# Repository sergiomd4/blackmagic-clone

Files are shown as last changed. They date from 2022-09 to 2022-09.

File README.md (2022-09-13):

Black Magic Clone
========================================

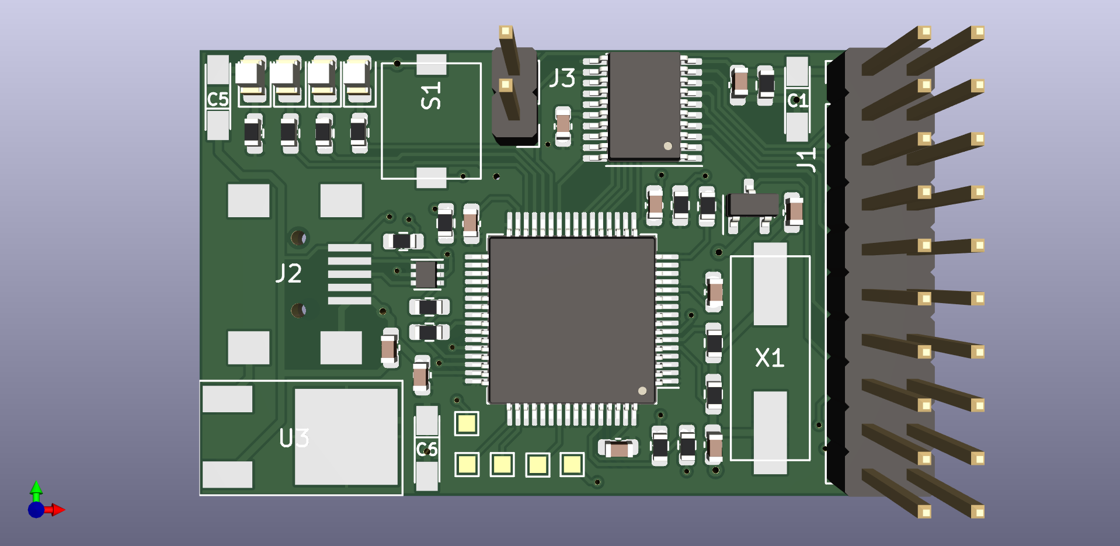
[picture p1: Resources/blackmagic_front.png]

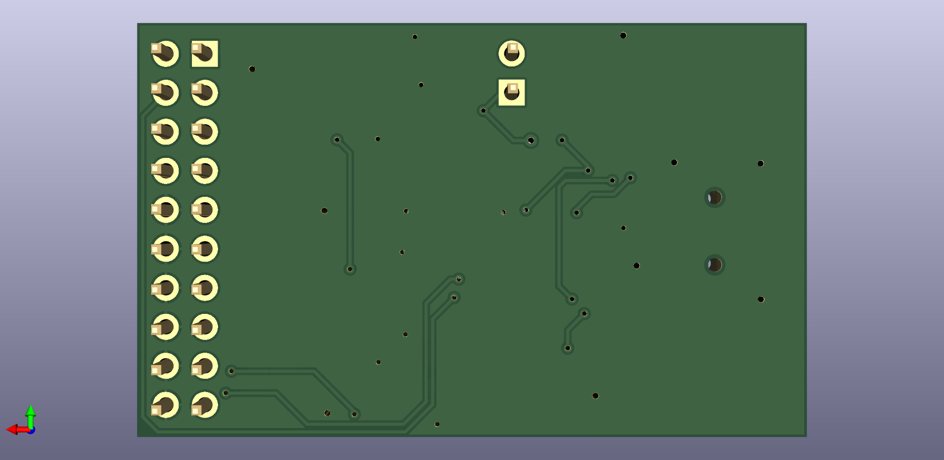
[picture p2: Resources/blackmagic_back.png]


Black Magic is an easy-to-use board used for debugging embedded microcontrollers. It supports several targets from manufacturers such as STMicroelectronics, Atmel, Nordic Semiconductor, NXP, Texas Instruments, Freescale, Silicon Labs, Xilinx or Raspberry Pi.

GNU debugger
-------------------
The Black Magic GNU DeBugger (GDB) server features:
* Automatic target detection
* No need for target specific configuration scripts
* Easily scriptable
* Interface to the host computer does not require special drivers
* Full debugging functionality
* Works with Windows, Linux and Mac environments

Repository Contents
-------------------

* **/Production** - Gerber files, drill files, BOM, CPL file
* **/Hardware** - KiCad PCB files, footprints library
* **/Documents** - Schematics pdf

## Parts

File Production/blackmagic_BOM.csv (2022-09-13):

Source: | C:\Users\Sergio\Documents\EOS\blackmagic-hardware-master\blackmagic_KiCAD\blackmagic.kicad_sch
Date: | 02/09/2022 14:07:15
Tool: | Eeschema (6.0.7)
Generator: | C:\Program Files\KiCad\6.0\bin\scripting\plugins/bom_csv_grouped_by_value.py
Component Count: | 40
Individual Components:
Item | Qty | Reference(s) | Value | LibPart | Footprint | Datasheet | LCSC Number Part
 |  | C1 | 10u | Device:C_Polarized | EOS:CASE-A_3216 | ~ | C7171
 |  | C2 | 100n | Device:C | Capacitor_SMD:C_0603_1608Metric | ~ | C1591
 |  | C3 | 18p | Device:C | Capacitor_SMD:C_0603_1608Metric | ~ | C1647
 |  | C4 | 18p | Device:C | Capacitor_SMD:C_0603_1608Metric | ~ | C1647
 |  | C5 | 10u | Device:C_Polarized | EOS:CASE-A_3216 | ~ | C7171
 |  | C6 | 10u | Device:C_Polarized | EOS:CASE-A_3216 | ~ | C7171
 |  | C7 | 100n | bmp_entropia-eagle-import:C-EUC0603 | Capacitor_SMD:C_0603_1608Metric |  | C1591
 |  | C8 | 100n | bmp_entropia-eagle-import:C-EUC0603 | Capacitor_SMD:C_0603_1608Metric |  | C1591
 |  | C9 | 100n | bmp_entropia-eagle-import:C-EUC0603 | Capacitor_SMD:C_0603_1608Metric |  | C1591
 |  | C10 | 100n | bmp_entropia-eagle-import:C-EUC0603 | Capacitor_SMD:C_0603_1608Metric |  | C1591
 |  | C11 | 100n | bmp_entropia-eagle-import:C-EUC0603 | Capacitor_SMD:C_0603_1608Metric |  | C1591
 |  | C12 | 100n | bmp_entropia-eagle-import:C-EUC0603 | Capacitor_SMD:C_0603_1608Metric |  | C1591
 |  | C13 | 100n | bmp_entropia-eagle-import:C-EUC0603 | Capacitor_SMD:C_0603_1608Metric |  | C1591
 |  | D1 | green | :LEDCHIPLED_0603_1 | LED_SMD:LED_0805_2012Metric |  | C434432
 |  | D2 | red | :LEDCHIPLED_0603_2 | LED_SMD:LED_0805_2012Metric |  | C434431
 |  | D3 | yellow | :LEDCHIPLED_0603_3 | LED_SMD:LED_0805_2012Metric |  | C434436
 |  | D4 | yellow | bmp_entropia-eagle-import:LEDCHIPLED_0603 | LED_SMD:LED_0805_2012Metric |  | C434436
 |  | J2 | USB_Mini_B | :USB_Mini_B_1 | EOS:U-M-M5SS-W-2 |  | C91144
 |  | Q1 | BC846 | Transistor_BJT:BC846 | Package_TO_SOT_SMD:SOT-23 | https://assets.nexperia.com/documents/data-sheet/BC846_SER.pdf | C2926206
 |  | R1 | 1k | Device:R | Resistor_SMD:R_0603_1608Metric | ~ | C21190
 |  | R2 | 22 | Device:R | Resistor_SMD:R_0603_1608Metric | ~ | C23345
 |  | R3 | 22 | Device:R | Resistor_SMD:R_0603_1608Metric | ~ | C23345
 |  | R4 | 1k5 | Device:R | Resistor_SMD:R_0603_1608Metric | ~ | C22843
 |  | R5 | 1k | Device:R | Resistor_SMD:R_0603_1608Metric | ~ | C21190
 |  | R6 | 10M | Device:R | Resistor_SMD:R_0603_1608Metric | ~ | C26097
 |  | R7 | 330 | Device:R | Resistor_SMD:R_0603_1608Metric | ~ | C23138
 |  | R8 | 390 | bmp_entropia-eagle-import:R-EU_R0603 | Resistor_SMD:R_0603_1608Metric |  | C23151
 |  | R9 | 390 | bmp_entropia-eagle-import:R-EU_R0603 | Resistor_SMD:R_0603_1608Metric |  | C23151
 |  | R10 | 390 | bmp_entropia-eagle-import:R-EU_R0603 | Resistor_SMD:R_0603_1608Metric |  | C23151
 |  | R11 | 390 | bmp_entropia-eagle-import:R-EU_R0603 | Resistor_SMD:R_0603_1608Metric |  | C23151
 |  | R12 | 1k | Device:R | Resistor_SMD:R_0603_1608Metric | ~ | C21190
 |  | R13 | 10k | Device:R | Resistor_SMD:R_0603_1608Metric | ~ | C25804
 |  | R14 | 1k | Device:R | Resistor_SMD:R_0603_1608Metric | ~ | C21190
 |  | R15 | 100 | Device:R | Resistor_SMD:R_0603_1608Metric | ~ | C22775
 |  | S1 | SW_Push | Switch:SW_Push | EOS:JPM1040-2013FC | ~ | C516061
 |  | U1 | TXS0108EPW | Logic_LevelTranslator:TXS0108EPW | Package_SO:TSSOP-20_4.4x6.5mm_P0.65mm | www.ti.com/lit/ds/symlink/txs0108e.pdf | C17206
 |  | U2 | USBLC6-2 | UNIclicker:USBLC6-2P6 | EOS:USBLC6-2P6 |  | C2827693
 |  | U3 | NCP1117 | blackmagic:NCP1117 | EOS:NCP1117DT12G |  | C897495
 |  | U4 | STM32F103RB | blackmagic:STM32F103RB | Package_QFP:LQFP-64_10x10mm_P0.5mm |  | C8735
 |  | X1 | 8 MHz | Device:Crystal | EOS:C08000J060 | ~ | C259040

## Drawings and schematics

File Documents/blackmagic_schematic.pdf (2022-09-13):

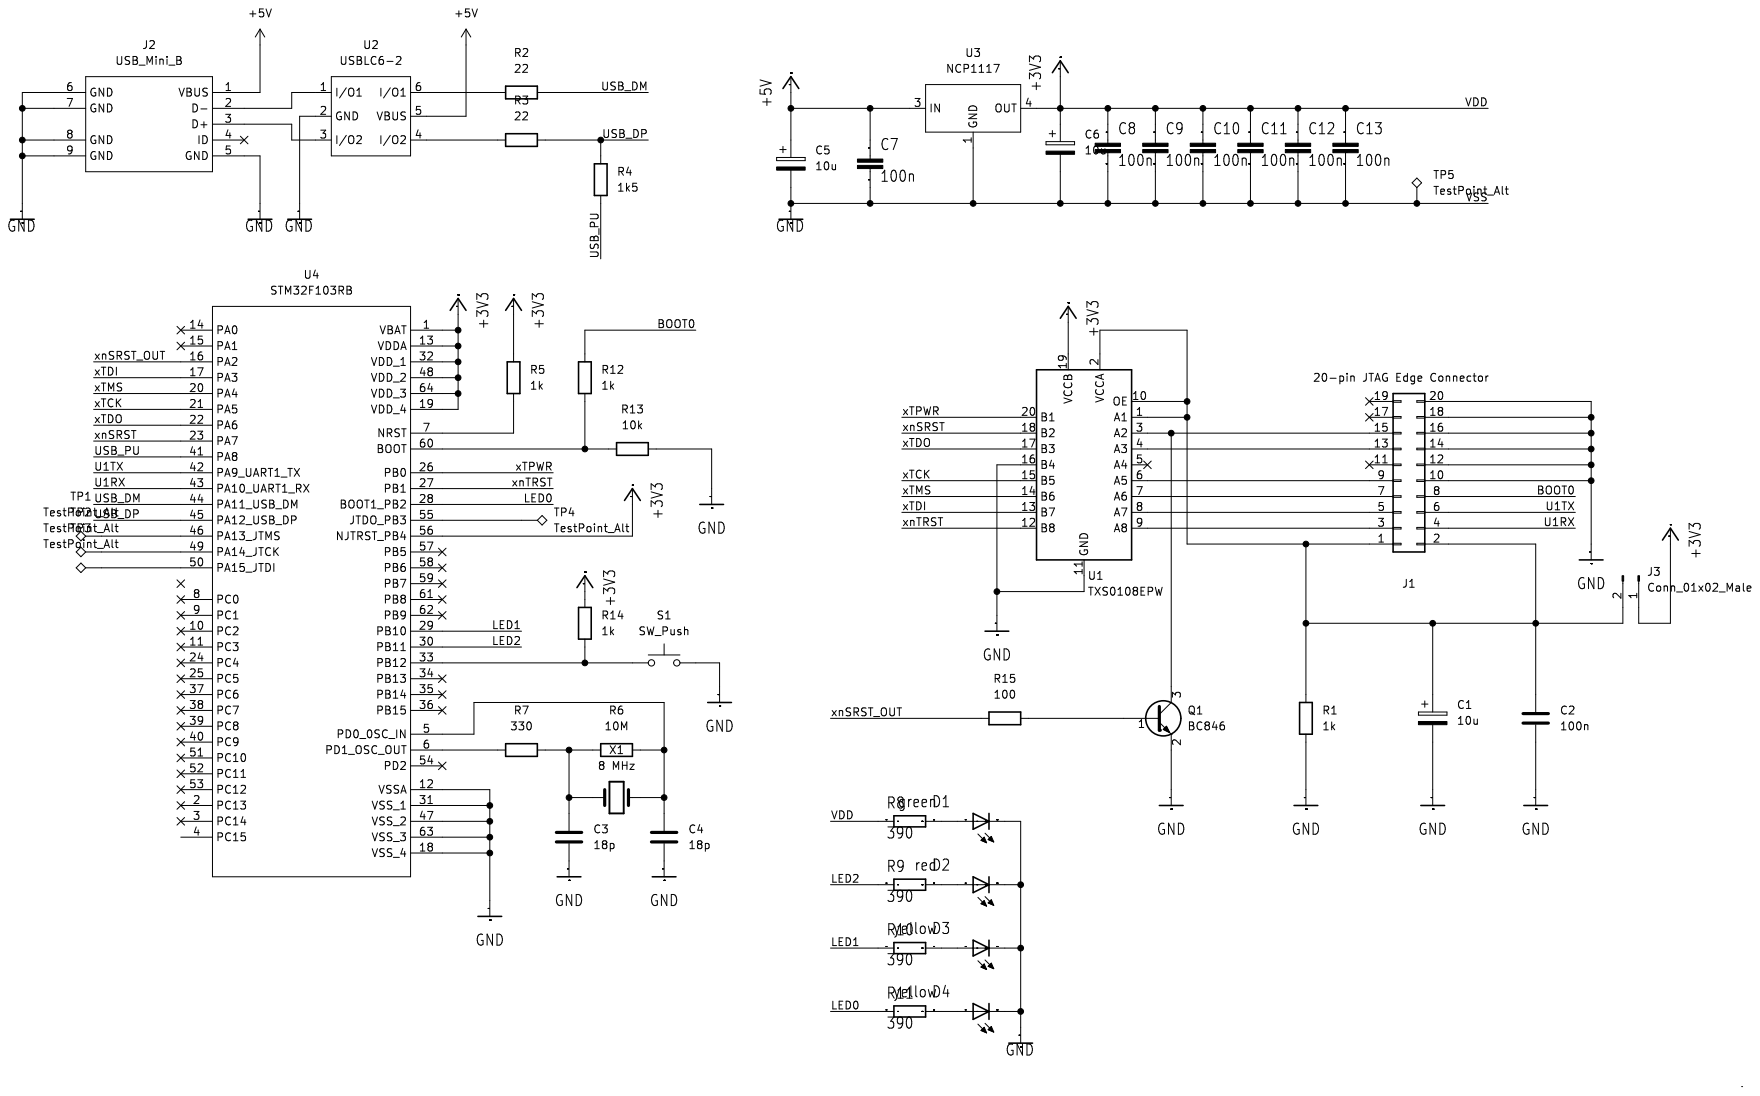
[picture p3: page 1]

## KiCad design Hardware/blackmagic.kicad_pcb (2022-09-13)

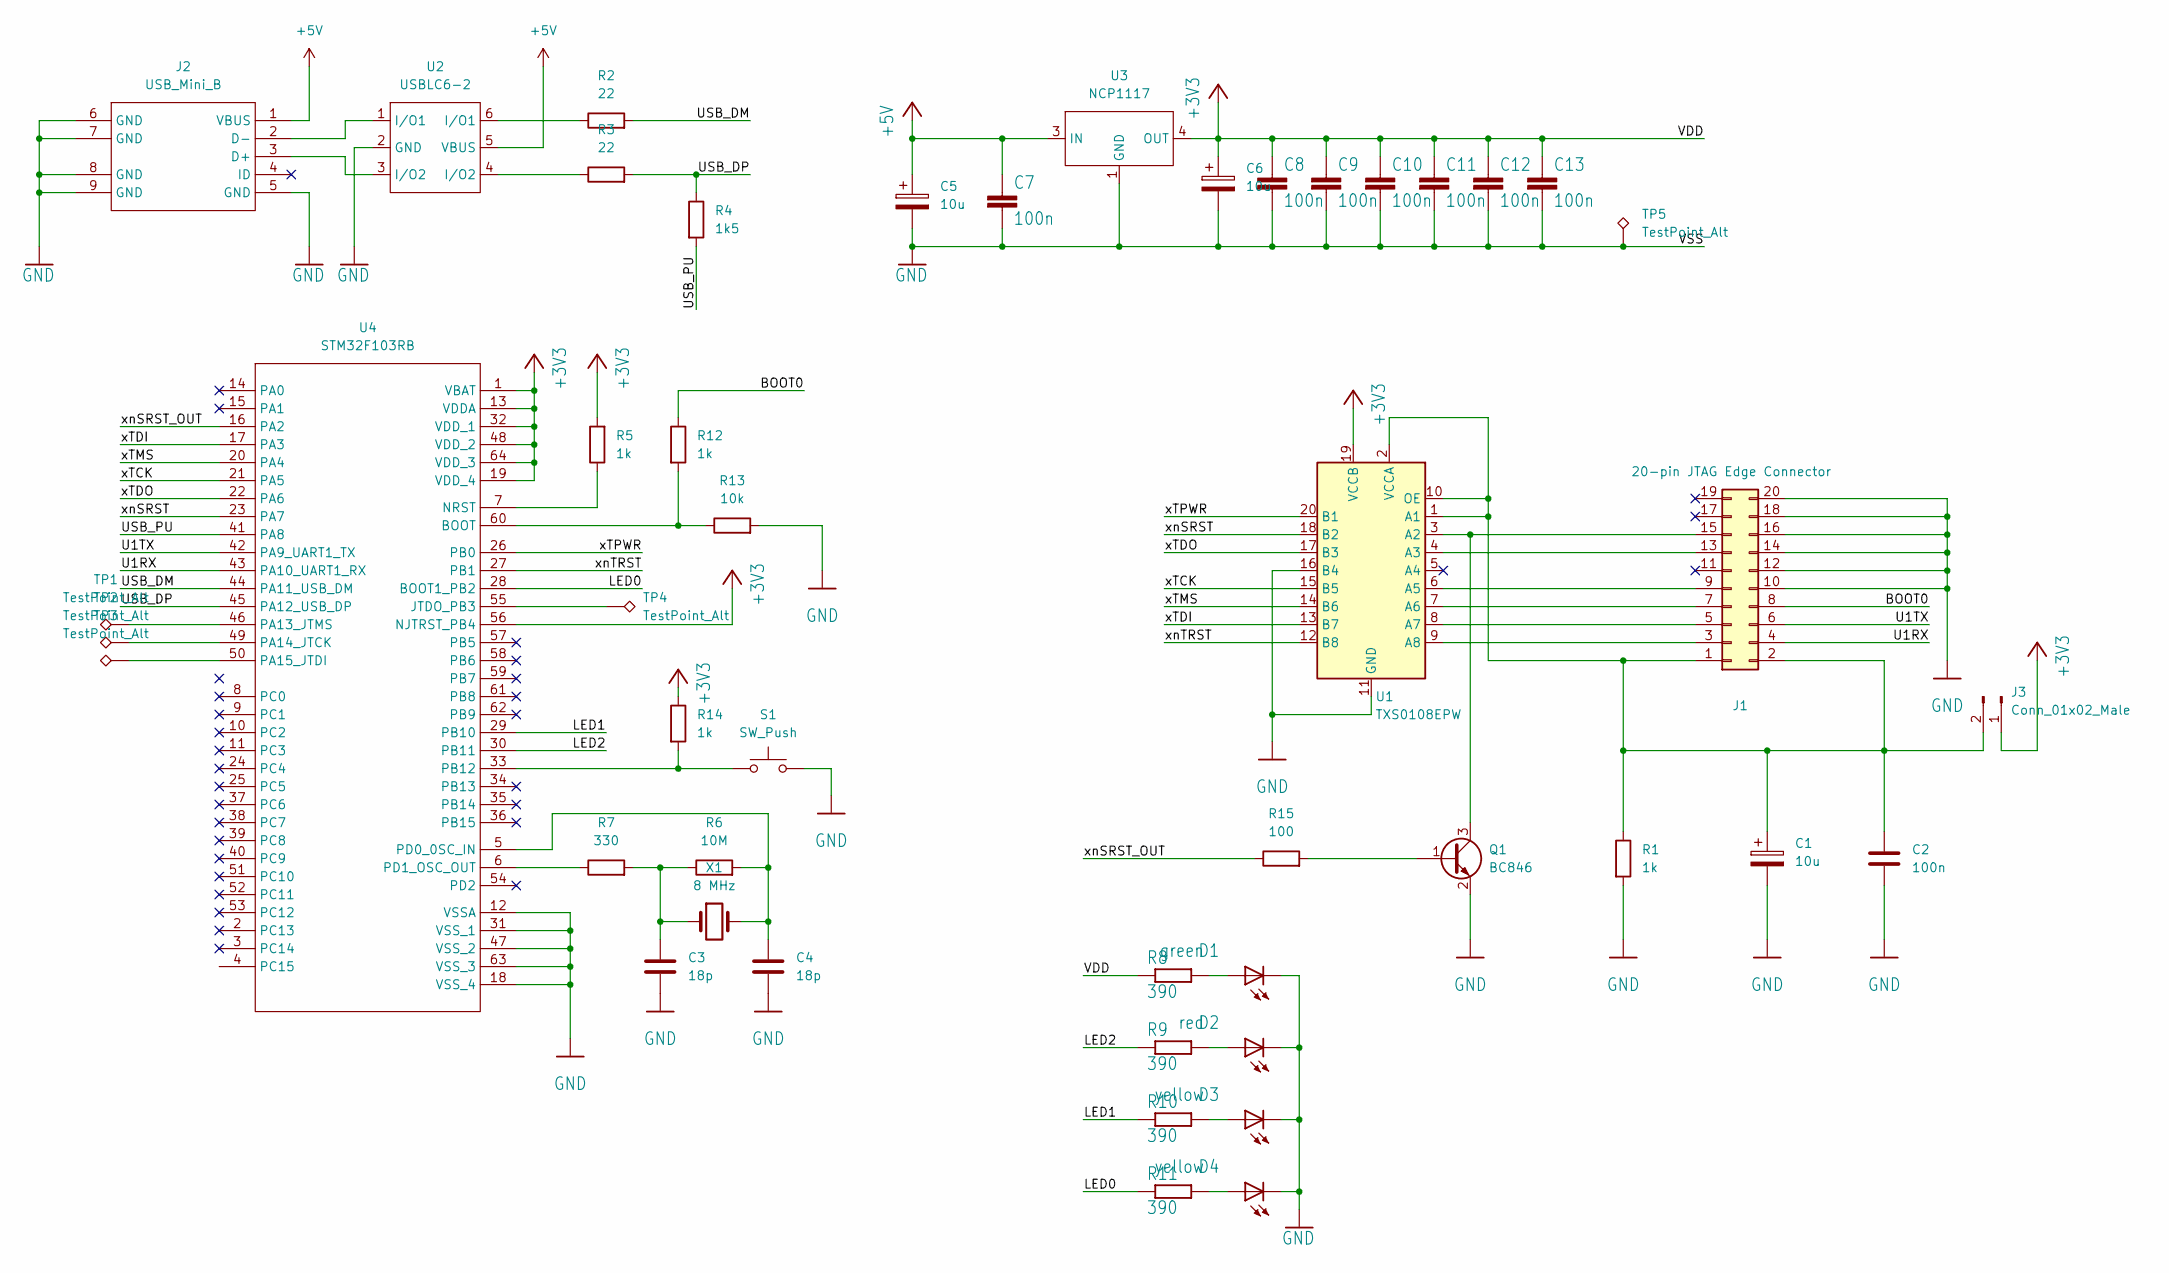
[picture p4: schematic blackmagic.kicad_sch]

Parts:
C1, C5, C6: 10u; CASE-A_3216; LCSC Number Part C7171
C2, C7, C8, C9, C10, C11, C12, C13: 100n; C_0603_1608Metric; LCSC Number Part C1591
C3, C4: 18p; C_0603_1608Metric; LCSC Number Part C1647
D1: green; LED_0805_2012Metric; LCSC Number Part C434432
D2: red; LED_0805_2012Metric; LCSC Number Part C434431
D3, D4: yellow; LED_0805_2012Metric; LCSC Number Part C434436
J1: 20-pin JTAG Edge Connector; PinHeader_2x10_P2.54mm_Vertical
J2: USB_Mini_B; U-M-M5SS-W-2; LCSC Number Part C91144
J3: Conn_01x02_Male; PinHeader_1x02_P2.54mm_Vertical
Q1: BC846; SOT-23; LCSC Number Part C2926206
R1, R5, R12, R14: 1k; R_0603_1608Metric; LCSC Number Part C21190
R2, R3: 22; R_0603_1608Metric; LCSC Number Part C23345
R4: 1k5; R_0603_1608Metric; LCSC Number Part C22843
R6: 10M; R_0603_1608Metric; LCSC Number Part C26097
R7: 330; R_0603_1608Metric; LCSC Number Part C23138
R8, R9, R10, R11: 390; R_0603_1608Metric; LCSC Number Part C23151
R13: 10k; R_0603_1608Metric; LCSC Number Part C25804
R15: 100; R_0603_1608Metric; LCSC Number Part C22775
S1: SW_Push; JPM1040-2013FC; LCSC Number Part C516061
TP1, TP2, TP3, TP4, TP5: TestPoint_Alt; TestPoint_Pad_1.0x1.0mm
U1: TXS0108EPW; TSSOP-20_4.4x6.5mm_P0.65mm; LCSC Number Part C17206
U2: USBLC6-2; USBLC6-2P6; LCSC Number Part C2827693
U3: NCP1117; NCP1117DT12G; LCSC Number Part C897495
U4: STM32F103RB; LQFP-64_10x10mm_P0.5mm; LCSC Number Part C8735
X1: 8 MHz; C08000J060; LCSC Number Part C259040

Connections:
+3V3: C6.1, C8.1, C9.1, C10.1, C11.1, C12.1, C13.1, J3.1, R5.2, R8.1, R14.1, U1.19 (VCCB), U3.4 (OUT), U4.1 (VBAT), U4.13 (VDDA), U4.19 (VDD_4), U4.32 (VDD_1), U4.48 (VDD_2), U4.56 (NJTRST_PB4), U4.64 (VDD_3)
+5V: C5.1, C7.1, J2.1 (VBUS), U2.5 (VBUS), U3.3 (IN)
/BOOT0: J1.8, R12.1
/LED0: R11.1, U4.28 (BOOT1_PB2)
/LED1: R10.1, U4.29 (PB10)
/LED2: R9.1, U4.30 (PB11)
/U1RX: J1.4, U4.43 (PA10_UART1_RX)
/U1TX: J1.6, U4.42 (PA9_UART1_TX)
/USB_DM: R2.2, U4.44 (PA11_USB_DM)
/USB_DP: R3.2, R4.1, U4.45 (PA12_USB_DP)
/USB_PU: R4.2, U4.41 (PA8)
/xTCK: U1.15 (B5), U4.21 (PA5)
/xTDI: U1.13 (B7), U4.17 (PA3)
/xTDO: U1.17 (B3), U4.22 (PA6)
/xTMS: U1.14 (B6), U4.20 (PA4)
/xTPWR: U1.20 (B1), U4.26 (PB0)
/xnSRST: U1.18 (B2), U4.23 (PA7)
/xnSRST_OUT: R15.1, U4.16 (PA2)
/xnTRST: U1.12 (B8), U4.27 (PB1)
GND: C1.2, C2.2, C3.2, C4.2, C5.2, C6.2, C7.2, C8.2, C9.2, C10.2, C11.2, C12.2, C13.2, D1.2 (C), D2.2 (C), D3.2 (C), D4.2 (C), J1.10, J1.12, J1.14, J1.16, J1.18, J1.20, J2.5 (GND), J2.6 (GND), J2.7 (GND), J2.8 (GND), J2.9 (GND), Q1.2 (E), R1.2, R13.2, S1.2, TP5.1, U1.11 (GND), U1.16 (B4), U2.2 (GND), U3.1 (GND), U4.12 (VSSA), U4.18 (VSS_4), U4.31 (VSS_1), U4.47 (VSS_2), U4.63 (VSS_3)
unnamed: C1.1, C2.1, J1.1, J1.2, J3.2, R1.1, U1.1 (A1), U1.2 (VCCA), U1.10 (OE)
unnamed: C3.1, R6.1, R7.2, X1.1
unnamed: C4.1, R6.2, U4.5 (PD0_0SC_IN), X1.2
unnamed: D1.1 (A), R8.2
unnamed: D2.1 (A), R9.2
unnamed: D3.1 (A), R10.2
unnamed: D4.1 (A), R11.2
unnamed: J1.3, U1.9 (A8)
unnamed: J1.5, U1.8 (A7)
unnamed: J1.7, U1.7 (A6)
unnamed: J1.9, U1.6 (A5)
unnamed: J1.13, U1.4 (A3)
unnamed: J1.15, Q1.3 (C), U1.3 (A2)
unnamed: J2.2 (D-), U2.1 (I/O1)
unnamed: J2.3 (D+), U2.3 (I/O2)
unnamed: Q1.1 (B), R15.2
unnamed: R2.1, U2.6 (I/O1)
unnamed: R3.1, U2.4 (I/O2)
unnamed: R5.1, U4.7 (NRST)
unnamed: R7.1, U4.6 (PD1_OSC_OUT)
unnamed: R12.2, R13.1, U4.60 (BOOT)
unnamed: R14.2, S1.1, U4.33 (PB12)
unnamed: TP3.1, U4.50 (PA15_JTDI)
unnamed: TP4.1, U4.55 (JTDO_PB3)
unnamed: TP1.1, U4.46 (PA13_JTMS)
unnamed: TP2.1, U4.49 (PA14_JTCK)

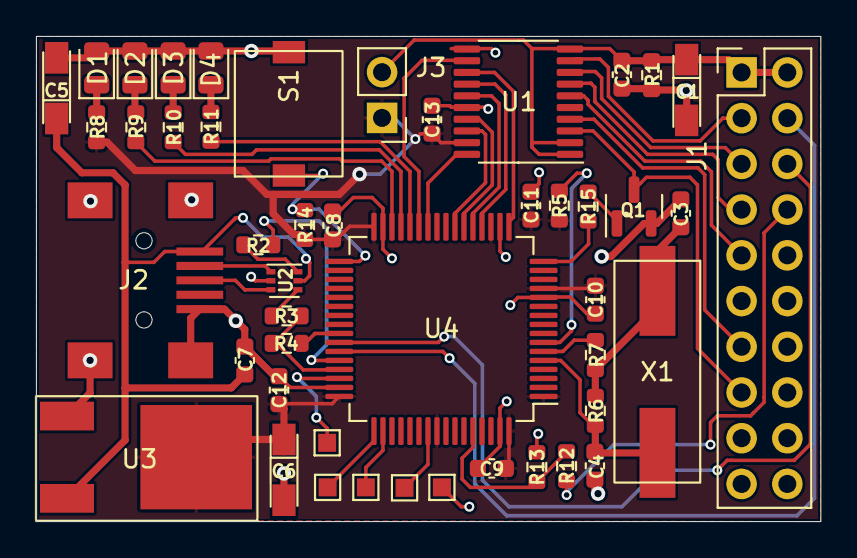
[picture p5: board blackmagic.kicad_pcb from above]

Board: 2 copper layers, 43.6 x 27.0 mm, 47 parts (0 on the bottom side), 46 nets.

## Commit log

2022-09-13 Add schematic
2022-09-13 Add KiCad files
    [blackmagic.kicad_pcb, blackmagic.kicad_sch]
2022-09-13 Add BOM
    [blackmagic_BOM.csv]
2022-09-13 Add CPL
    [blackmagic-all-pos.csv]
2022-09-13 Add Drill Files
    [blackmagic-NPTH.drl, blackmagic-PTH.drl]
2022-09-13 Add Gerber Files
    [blackmagic-B_Cu.gbr, blackmagic-B_Mask.gbr, blackmagic-B_Paste.gbr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]
2022-09-13 Add footprints library
